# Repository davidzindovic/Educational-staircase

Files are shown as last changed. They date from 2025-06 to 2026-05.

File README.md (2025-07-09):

# Musical stairs with video effects
This project was constructed for use on the Faculty of Education, University of Ljubljana. The goal was to create attachable hardware to put onto an existing staircase (covering half the surface) with 2 turns and 25 steps.
Input data is processed by an ESP32, musical effects are played from an SD card with the help od MP3-TF player and visual effects are displayed on a projection/ screen via Raspberry Pi.
Data is transmitted from the ESP32 to RPI via Bluetooth.

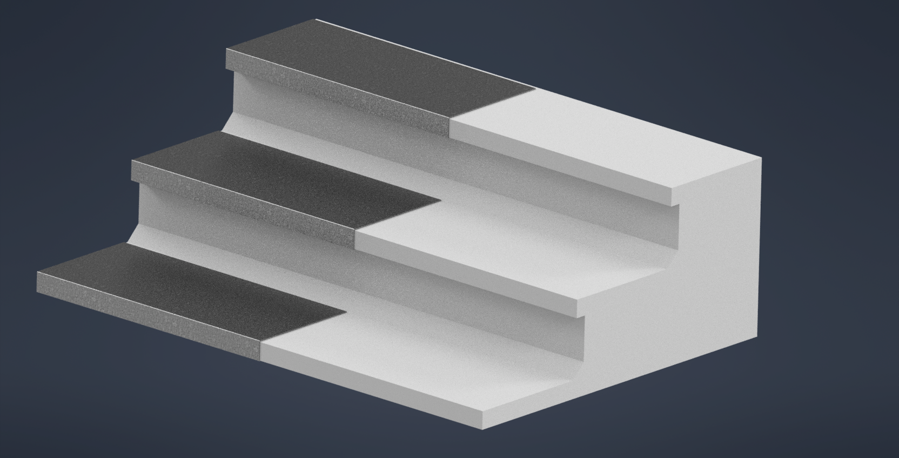
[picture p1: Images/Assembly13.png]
Part of the staircase with added hardware

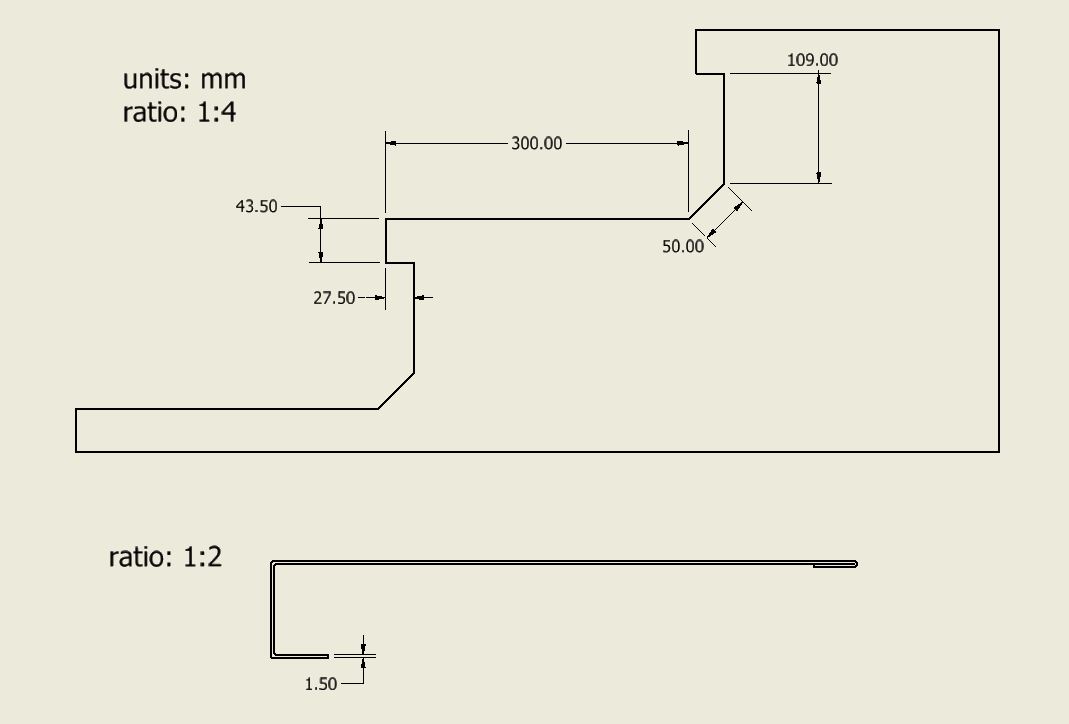
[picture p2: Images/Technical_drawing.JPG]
Technical Drawing


# Hardware
- ESP32
- MP3-TF player module
- Mux 4051
- Raspberry Pi 5
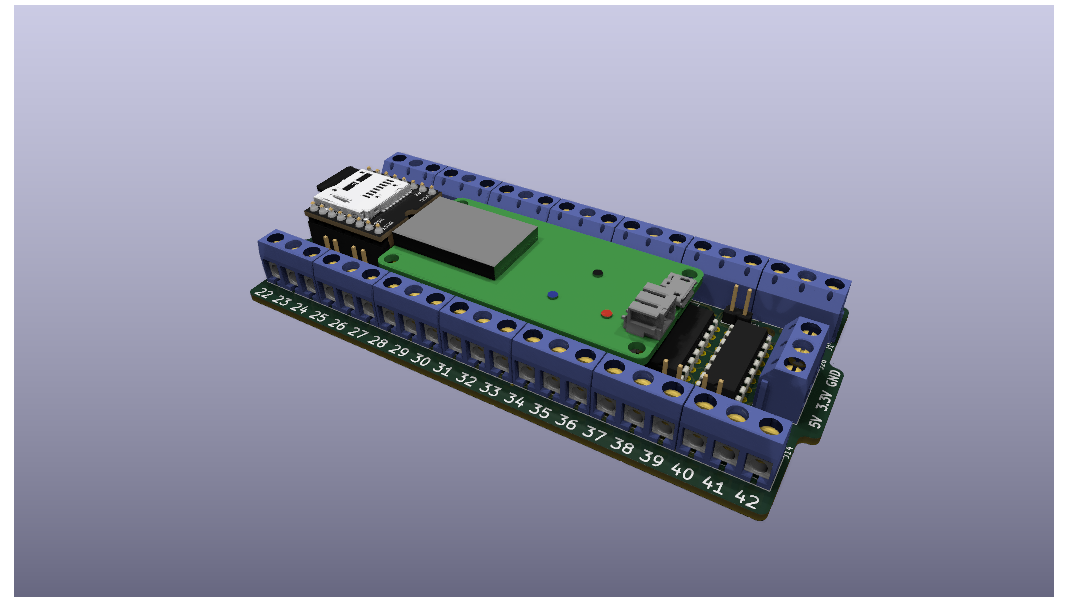
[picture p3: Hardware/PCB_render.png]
PCB render


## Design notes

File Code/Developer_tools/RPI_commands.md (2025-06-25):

# Launch python file

Do this in root (~$)
```
python -m venv name_of_virutal_env
source name_of_virtual_env/bin/activate
```
Now you should navigate to the folders/scripts.

# Transfer file from RPI to WIN PC
Putty should be installed on WIN PC prior to this step. Don't forget to check the "Add to PATH option".
```
pscp.exe pi_name@device name:_absolute_path_to_file absolute_path_to_paste_file
```

# Transfer file from WIN PC to RPI
```
scp absolute_path_to_file pi_name@device name:_absolute_path_to_paste_file
```

In both casses you will need to enter the RPI password, which will not be visible when typing.

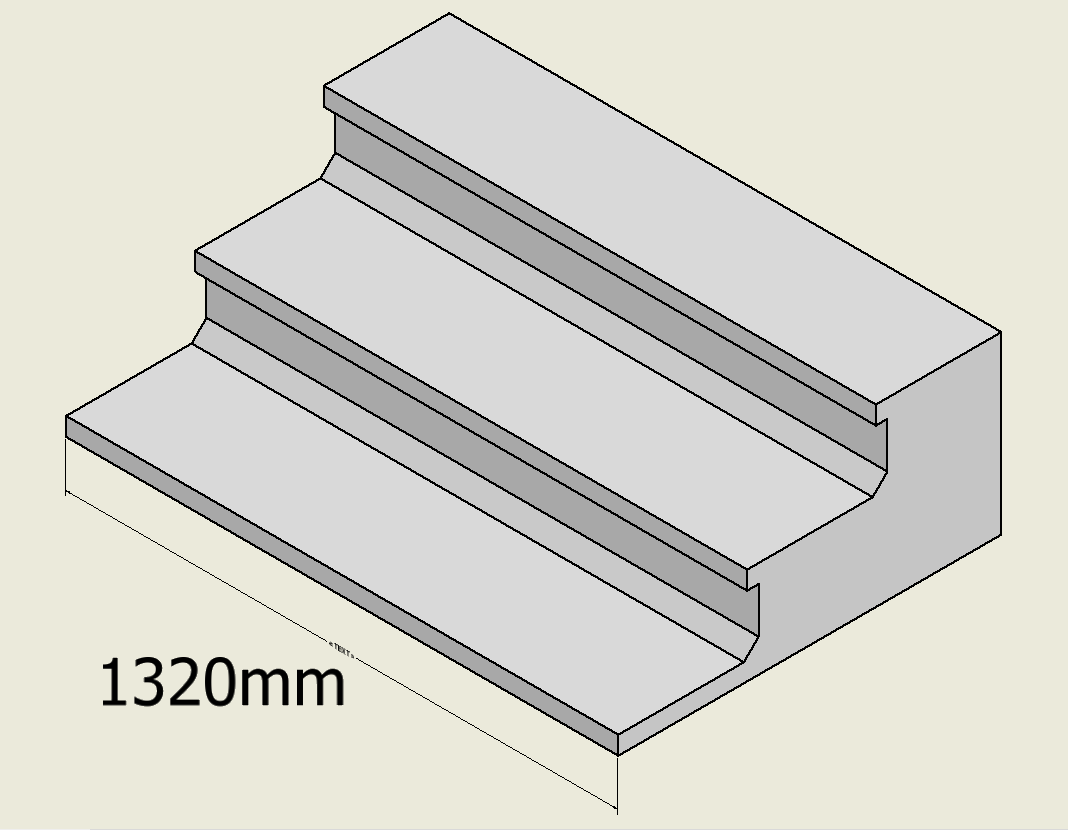
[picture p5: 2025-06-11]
Images/part_of_staircase.png

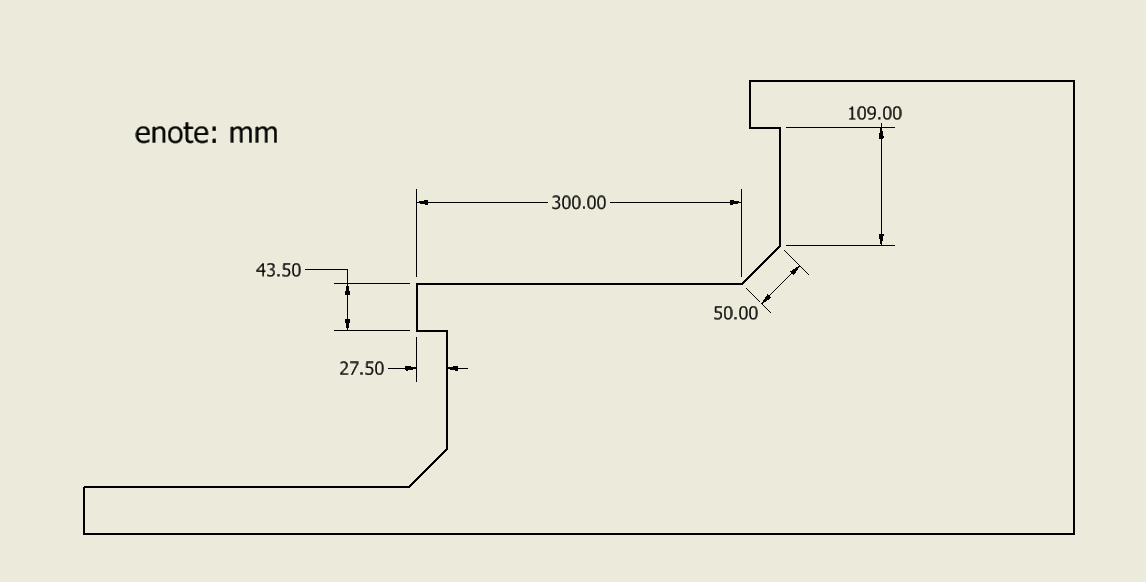
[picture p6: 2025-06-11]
Images/Staircase_dimensions.png

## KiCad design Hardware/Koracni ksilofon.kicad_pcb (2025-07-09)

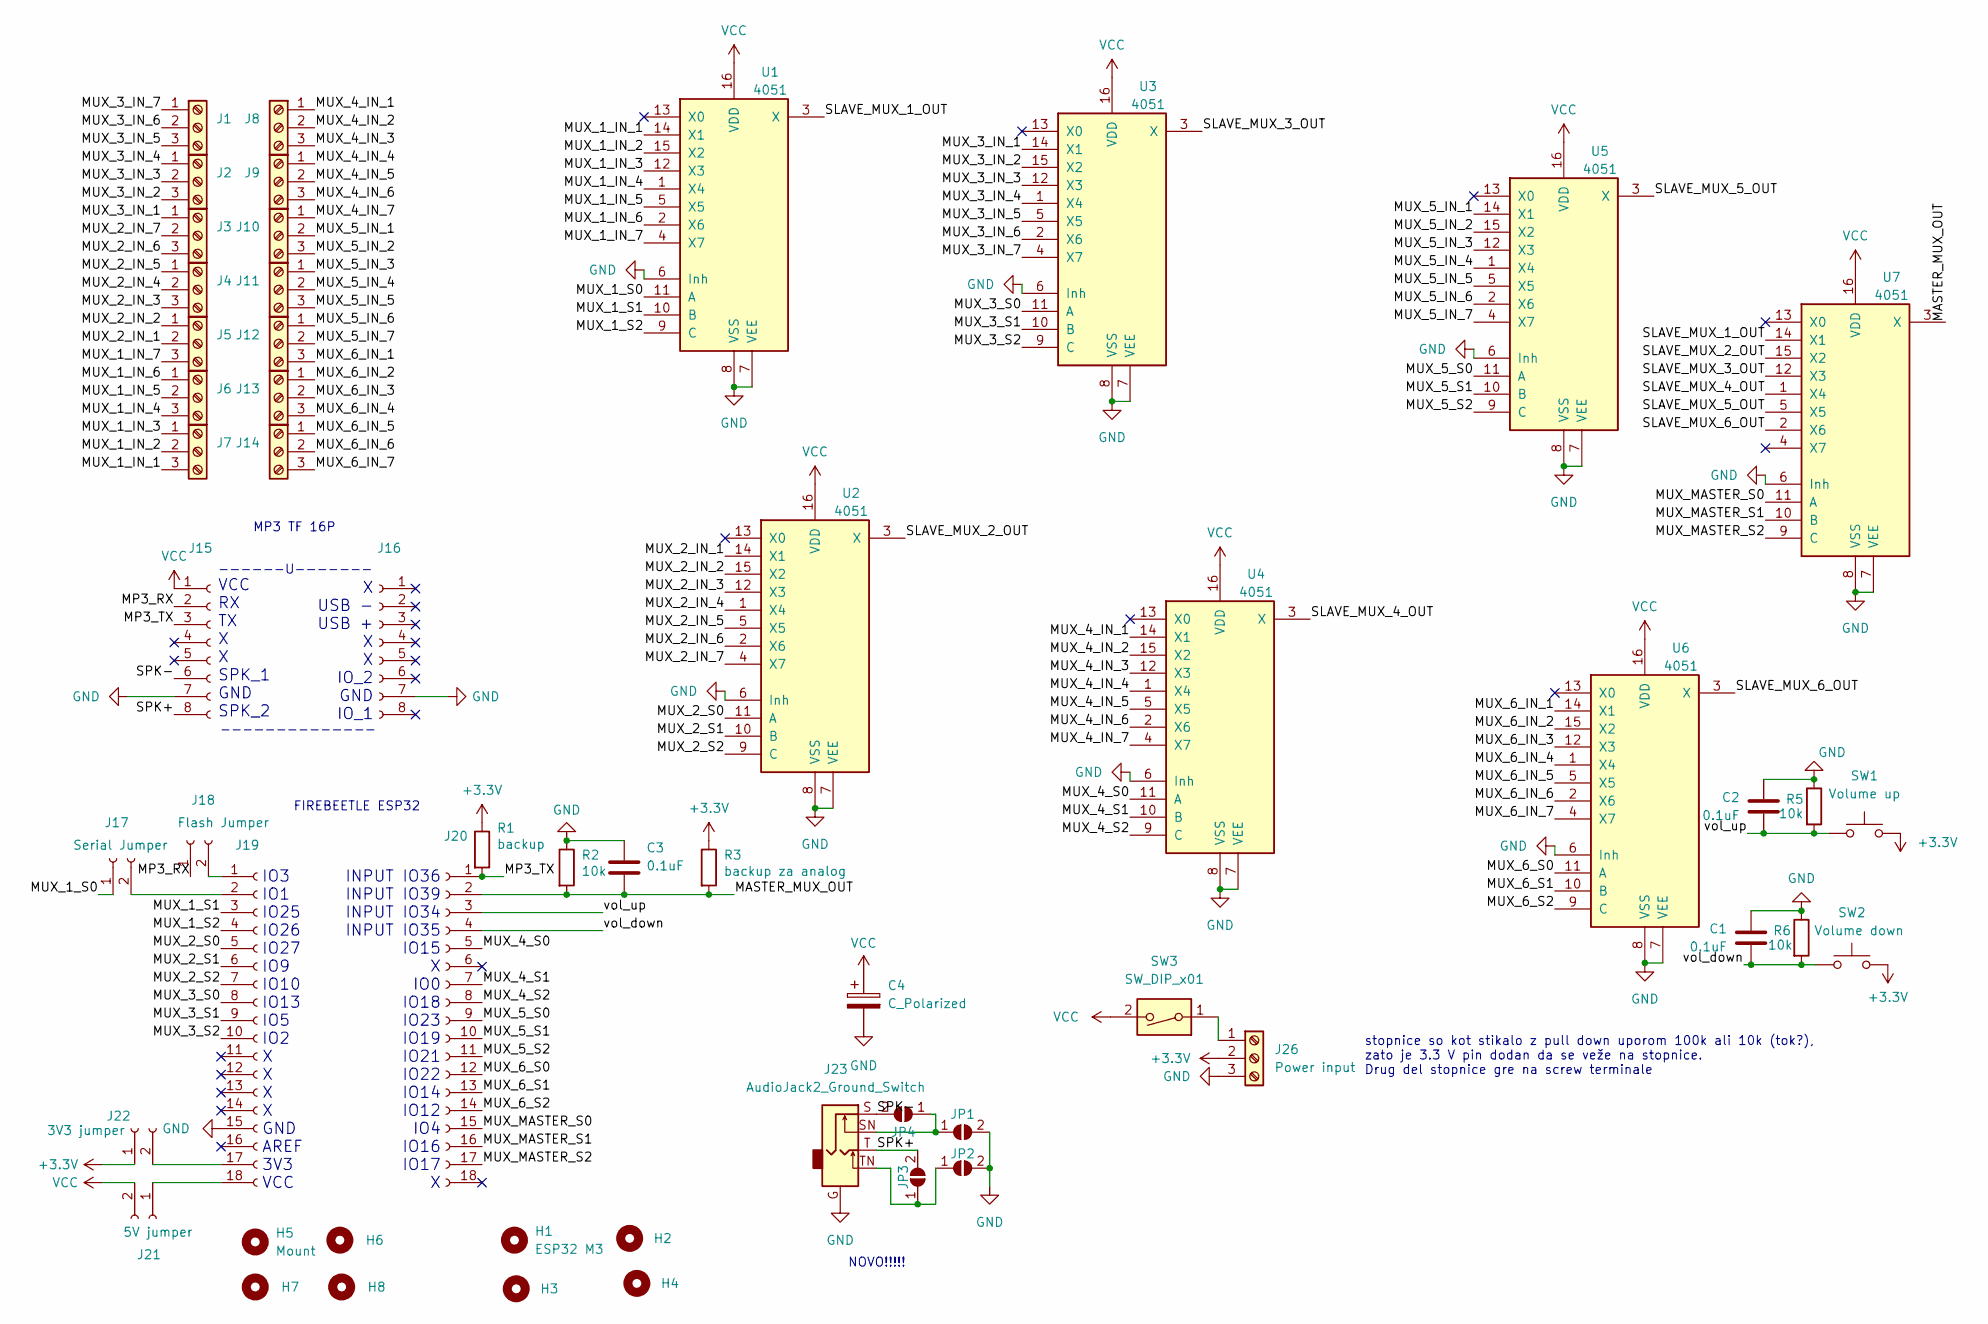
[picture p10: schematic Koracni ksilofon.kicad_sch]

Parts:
C1, C2, C3: 0.1uF; C_Disc_D3.4mm_W2.1mm_P2.50mm
C4: C_Polarized; CP_Radial_D5.0mm_P2.50mm
H1, H2, H3, H4: ESP32 M3; M3 luknja
H5, H6, H7, H8: Mount; MountingHole_3.2mm_M3
J1, J2, J3, J4, J5, J6, J7, J8, J9, J10, J11, J12, J13, J14: Screw_Terminal_01x03; TerminalBlock_bornier-3_P5.08mm
J15, J16: Conn_01x08_Socket; PinSocket_1x08_P2.54mm_Vertical
J17: Serial Jumper; PinHeader_1x02_P2.54mm_Vertical
J18: Flash Jumper; PinHeader_1x02_P2.54mm_Vertical
J19, J20: Conn_01x18_Socket; PinSocket_1x18_P2.54mm_Vertical
J21: 5V jumper; PinHeader_1x02_P2.54mm_Vertical
J22: 3V3 jumper; PinHeader_1x02_P2.54mm_Vertical
J23: AudioJack2_Ground_Switch; Audio jack connector
J26: Power input; TerminalBlock_bornier-3_P5.08mm
JP1, JP2, JP3, JP4: SolderJumper_2_Open; SolderJumper-2_P1.3mm_Open_TrianglePad1.0x1.5mm
R1: backup; R_Axial_DIN0207_L6.3mm_D2.5mm_P7.62mm_Horizontal
R2, R5, R6: 10k; R_Axial_DIN0207_L6.3mm_D2.5mm_P7.62mm_Horizontal
R3: backup za analog; R_Axial_DIN0207_L6.3mm_D2.5mm_P7.62mm_Horizontal
SW1: Volume up; PinHeader_1x02_P2.54mm_Vertical
SW2: Volume down; PinHeader_1x02_P2.54mm_Vertical
SW3: SW_DIP_x01; PinHeader_1x02_P2.54mm_Vertical
U1, U2, U3, U4, U5, U6, U7: 4051; DIP-16_W7.62mm

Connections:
+3.3V: J22.1, J26.2, R1.1, R3.1, SW1.2, SW2.2
/MASTER_MUX_OUT: C3.2, J20.2, R2.2, R3.2, U7.3 (X)
/MP3_RX: J15.2, J18.1
/MP3_TX: J15.3, J20.1, R1.2
/MUX_1_IN_1: J7.3, U1.14 (X1)
/MUX_1_IN_2: J7.2, U1.15 (X2)
/MUX_1_IN_3: J7.1, U1.12 (X3)
/MUX_1_IN_4: J6.3, U1.1 (X4)
/MUX_1_IN_5: J6.2, U1.5 (X5)
/MUX_1_IN_6: J6.1, U1.2 (X6)
/MUX_1_IN_7: J5.3, U1.4 (X7)
/MUX_1_S0: J17.1, U1.11 (A)
/MUX_1_S1: J19.3, U1.10 (B)
/MUX_1_S2: J19.4, U1.9 (C)
/MUX_2_IN_1: J5.2, U2.14 (X1)
/MUX_2_IN_2: J5.1, U2.15 (X2)
/MUX_2_IN_3: J4.3, U2.12 (X3)
/MUX_2_IN_4: J4.2, U2.1 (X4)
/MUX_2_IN_5: J4.1, U2.5 (X5)
/MUX_2_IN_6: J3.3, U2.2 (X6)
/MUX_2_IN_7: J3.2, U2.4 (X7)
/MUX_2_S0: J19.5, U2.11 (A)
/MUX_2_S1: J19.6, U2.10 (B)
/MUX_2_S2: J19.7, U2.9 (C)
/MUX_3_IN_1: J3.1, U3.14 (X1)
/MUX_3_IN_2: J2.3, U3.15 (X2)
/MUX_3_IN_3: J2.2, U3.12 (X3)
/MUX_3_IN_4: J2.1, U3.1 (X4)
/MUX_3_IN_5: J1.3, U3.5 (X5)
/MUX_3_IN_6: J1.2, U3.2 (X6)
/MUX_3_IN_7: J1.1, U3.4 (X7)
/MUX_3_S0: J19.8, U3.11 (A)
/MUX_3_S1: J19.9, U3.10 (B)
/MUX_3_S2: J19.10, U3.9 (C)
/MUX_4_IN_1: J8.1, U4.14 (X1)
/MUX_4_IN_2: J8.2, U4.15 (X2)
/MUX_4_IN_3: J8.3, U4.12 (X3)
/MUX_4_IN_4: J9.1, U4.1 (X4)
/MUX_4_IN_5: J9.2, U4.5 (X5)
/MUX_4_IN_6: J9.3, U4.2 (X6)
/MUX_4_IN_7: J10.1, U4.4 (X7)
/MUX_4_S0: J20.5, U4.11 (A)
/MUX_4_S1: J20.7, U4.10 (B)
/MUX_4_S2: J20.8, U4.9 (C)
/MUX_5_IN_1: J10.2, U5.14 (X1)
/MUX_5_IN_2: J10.3, U5.15 (X2)
/MUX_5_IN_3: J11.1, U5.12 (X3)
/MUX_5_IN_4: J11.2, U5.1 (X4)
/MUX_5_IN_5: J11.3, U5.5 (X5)
/MUX_5_IN_6: J12.1, U5.2 (X6)
/MUX_5_IN_7: J12.2, U5.4 (X7)
/MUX_5_S0: J20.9, U5.11 (A)
/MUX_5_S1: J20.10, U5.10 (B)
/MUX_5_S2: J20.11, U5.9 (C)
/MUX_6_IN_1: J12.3, U6.14 (X1)
/MUX_6_IN_2: J13.1, U6.15 (X2)
/MUX_6_IN_3: J13.2, U6.12 (X3)
/MUX_6_IN_4: J13.3, U6.1 (X4)
/MUX_6_IN_5: J14.1, U6.5 (X5)
/MUX_6_IN_6: J14.2, U6.2 (X6)
/MUX_6_IN_7: J14.3, U6.4 (X7)
/MUX_6_S0: J20.12, U6.11 (A)
/MUX_6_S1: J20.13, U6.10 (B)
/MUX_6_S2: J20.14, U6.9 (C)
/MUX_MASTER_S0: J20.15, U7.11 (A)
/MUX_MASTER_S1: J20.16, U7.10 (B)
/MUX_MASTER_S2: J20.17, U7.9 (C)
/SLAVE_MUX_1_OUT: U1.3 (X), U7.14 (X1)
/SLAVE_MUX_2_OUT: U2.3 (X), U7.15 (X2)
/SLAVE_MUX_3_OUT: U3.3 (X), U7.12 (X3)
/SLAVE_MUX_4_OUT: U4.3 (X), U7.1 (X4)
/SLAVE_MUX_5_OUT: U5.3 (X), U7.5 (X5)
/SLAVE_MUX_6_OUT: U6.3 (X), U7.2 (X6)
/SPK+: J15.8, J23.T, JP3.2 (B)
/SPK-: J15.6, J23.S, JP4.2 (B)
/vol_down: C1.2, J20.4, R6.2, SW2.1
/vol_up: C2.2, J20.3, R5.2, SW1.1
GND: C1.1, C2.1, C3.1, C4.2, J15.7, J16.7, J19.15, J23.G, J26.3, JP1.2 (B), JP2.2 (B), R2.1, R5.1, R6.1, U1.6 (Inh), U1.7 (VEE), U1.8 (VSS), U2.6 (Inh), U2.7 (VEE), U2.8 (VSS), U3.6 (Inh), U3.7 (VEE), U3.8 (VSS), U4.6 (Inh), U4.7 (VEE), U4.8 (VSS), U5.6 (Inh), U5.7 (VEE), U5.8 (VSS), U6.6 (Inh), U6.7 (VEE), U6.8 (VSS), U7.6 (Inh), U7.7 (VEE), U7.8 (VSS)
unnamed: J17.2, J19.2
unnamed: J18.2, J19.1
unnamed: J19.17, J22.2
unnamed: J19.18, J21.1
unnamed: J26.1, SW3.1
unnamed: J23.SN, JP1.1 (A), JP4.1 (A)
unnamed: J23.TN, JP2.1 (A), JP3.1 (A)
VCC: C4.1, J15.1, J21.2, SW3.2, U1.16 (VDD), U2.16 (VDD), U3.16 (VDD), U4.16 (VDD), U5.16 (VDD), U6.16 (VDD), U7.16 (VDD)

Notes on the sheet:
stopnice so kot stikalo z pull down uporom 100k ali 10k (tok?), zato je 3.3 V pin dodan da se veže na stopnice. Drug del stopnice gre na screw terminale
--------------
X USB - USB + X X IO_2 GND IO_1
NOVO!!!!!
FIREBEETLE ESP32
INPUT IO36 INPUT IO39 INPUT IO34 INPUT IO35 IO15 X IO0 IO18 IO23 IO19 IO21 IO22 IO14 IO12 IO4 IO16 IO17 X
IO3 IO1 IO25 IO26 IO27 IO9 IO10 IO13 IO5 IO2 X X X X GND AREF 3V3 VCC
MP3 TF 16P
VCC RX TX X X SPK_1 GND SPK_2
------U-------

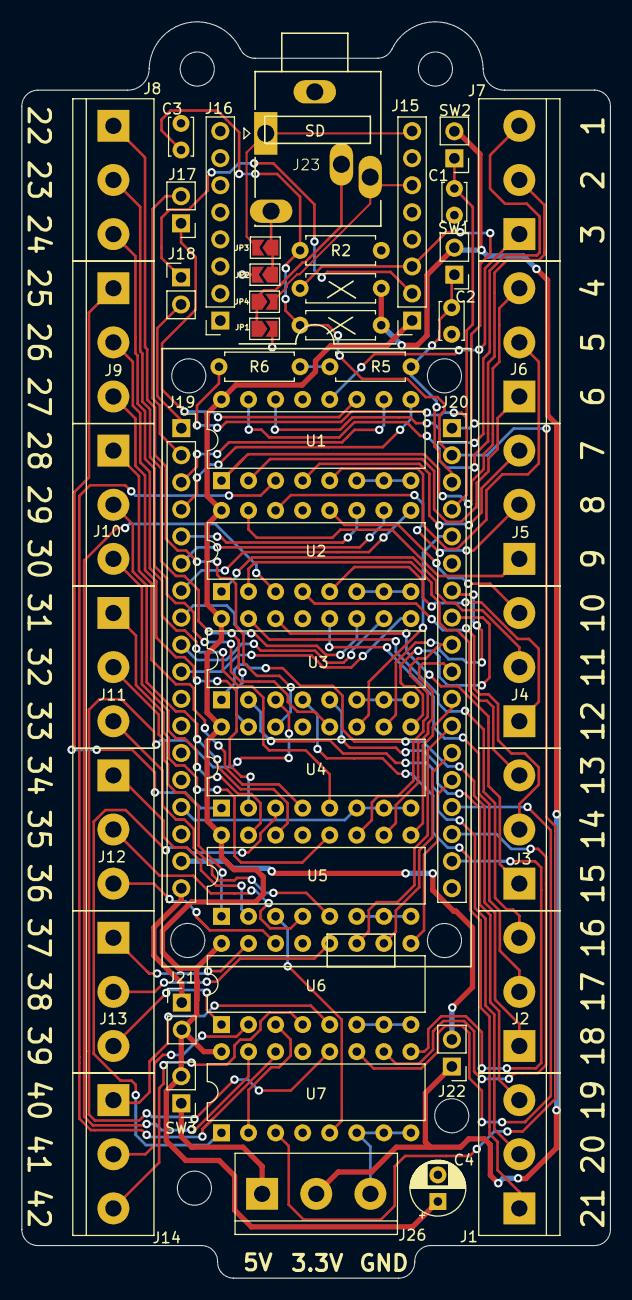
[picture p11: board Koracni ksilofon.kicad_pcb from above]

Board: 2 copper layers, 55.2 x 117.9 mm, 55 parts (0 on the bottom side), 86 nets.

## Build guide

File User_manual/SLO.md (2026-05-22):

# Navodila za uporabo
Didaktično stopnišče je nadgradnja obstoječega stopnišča, ki omogoča obogatitev sprehajalčeve poti po nadstropjih s pomočjo zvočnih in vizualnih učinkov. Korak na vsako stopnico sproži nov zvočni učinek, ki ga lahko odgovorna oseba spremeni z nalaganjem zvočnih datotek na SD kartico. Odziv na korak ni nujno le zvočen, saj v primeru prisotnosti primerno pripravljenega USB ključka se bodo tudi primerne vsebine predvajale na projekciji. Odgovorne osebe lahko pripravijo naloge (enačbe, povezovanje besed in slik, stopmotion, mešanje barv) ali pa diaprojekcijo.

# Zvočni učinki
Datoteke za zvočne učinke se bodo predvajale, ko stopimo na stopnico. V primeru, da se trenutna skladba še ni končala, in stopimo na naslednjo stopnico, potem bo trenutna skladba prekinjena in nova se bo predvajala.
Za prenos datotek za zvočne učinke na napravo uporabimo SD kartico.

### SD kartica
Opozorila:
- Na SD kartici naj bo največ 22 skladb (ker je 22 stopnic vse skupaj v uporabi).
  - SD kartico je potrebno v primeru nakupa nova SD kartice ponastaviti s pomočjo "SD Card Formatter".
- Skladbe morajo biti v formatu MP3.
  - To lahko preverite tako, da:
    * kliknete enkrat na datoteko (skladbo) z levim klikom
    * nato enkrat z desnim klikom
    * na dnu okenca kliknete "Lastnosti".
    * Če vidite kje napisano ".mp3", potem je datoteka pripravljena
  - V primeru, da vaša datoteka ni v formatu MP3, lahko vašo datoteko pretvorite v MP3 s pomočjo https://online-audio-converter.com/
  - Za lažje beleženja zaporedja zvokov lahko skladbe poimenujete s številkami ("1", "2" ...)
***

# Vizualni učinki
Datoteke za vizualne učinke se bodo predvajale glede na vaša navodila na USB ključku.
Možni vizualni učinki oz. aplikacije so:
- Enostavno mešanje barv
  - Vsak korak na stopnico doda eno barvo. Ko dosežemo mejo za barve, je prikazan rezultat. 
- Kompleksno mešanje barv
  - Vsak korak na stopnico doda eno barvo. Rezultat je prikazan sproti, aplikacija se ne konča, razen če uporabnik to zahteva
- Enačba
  - Korak na primerno stopnico predstavlja vnos rešitve. Pri tem lahko uporabimo le prvih deset stopnic (za vnos številk 0-9).
  - V primeru, da želimo vnesti večmestno številko, to storimo tako, da stopimo na stopnico za vnos vsake števke od leve proti desni.
- Povezovanje slik in besed
  - Korak na primerno stopnico (1 do x) predstavlja vnos rešitve
  - Slike morajo biti poimenovane s številko
  - Beseda mora biti v obliki sliki in poimenovana enako kot v ukazu
- Stopmotion
  - Začnemo s prvo sliko
  - Premik na naslednjo sliko dosežemo s korakom na naslednjo stopnico
  - Sliko lahko premaknemo nazaj s korakom na prješnjo stopnico
- Slideshow
  - Samodejno predvajanje videoposnetkov in/ali slik
  - Nastavljiv način

Opozorilo: Za izbiro barve uporabite Color Picker na Googlu: https://g.co/kgs/LrNHnkX . S pomočjo okna in drsnika izberite barvo in prekopirajte napis zapisan pod "HEX" (npr. #fcba03).

### Ukazi za vizualne učinke
Svoja navodila napišete tako, da v tekstovno datoteko "izvedba" na USB ključku vpišete ukaze v obliki, ki je primerna za aplikacijo:
- Enostavno mešanje barv: `barve:simple;število_možnih_vnosov!barva_hex_1,barva_hex_2`
  - Do vsake izmed napisanih HEX barv lahko dostopamo z eno stopnico.
  - primer: `barve:simple;3!#eb4034,#eb4034,#495446,#aba295,#8a6a91`
**slika primera**
- Kompleksno mešanje barv: `barve:complex;število_možnih_vnosov!barva_hex_1,barva_hex_2`
  - Do vsake izmed napisanih HEX barv lahko dostopamo z eno stopnico.
  - primer: `barve:complex;3!#eb4034,#eb4034,#495446,#aba295,#8a6a91`
**slika primera**
- Enačba: `enacba:ime_mape_s_slikami_stevilk;x+y_=z$resitev`
  - pri računu nam `_` skrije rešitev, vendar mora biti toliko znakov kot števk v rešitvi.
  - skrijemo lahko katerikoli del enačbe
  - na koncu moramo zapisati rešitev po `$`
  - primer: `enacba:naloga1;1+__=50$49`
**slika primera**
- Povezovanje slik in besed: `besedilna:ime_mape_s_slikami;ime_slike_z_napisom$stevilka_slike_ki_je_pravilna`
  - primer: `besedilna:naloga1;papagaj$3`
**slika primera**
- Stopmotion: `stopmotion:ime_mape_z_vsebino;neki?`
  - primer: `stopmotion:prva_animacija;1`
- Slideshow: `slideshow:ime_mape_z_vsebino;koliko_casa_naj_prikazuje_sliko$nacin_predvajanja`
  - nacini predvajanja:
    - 1 = le enkrat predvajaj samo slike
    - 2 = le enkrat predvajaj samo videoposnetke
    - 3 = le enkrat predvajaj slike in videoposnetke
    - 4 = ponavljaj predvajanje samo slik
    - 5 = ponavljaj predvajanje samo videposnetkov
    - 6 = ponavljaj predvajanje slik in videoposnetkov
  - primer `slideshow:ponedeljek;3$3`

### Preizkus ukazov za vizualne učinke

### USB ključek
Opozorila:
- USB ključek mora biti imenovan "stopnice"
  - USB ključek lahko preimenujete tako, da:
    * odprete Raziskovalec (ikona z mapico)
    * na levi strani najdete vstavljen USB ključek
    * enkrat z levim klikom kliknete na USB ključek
    * enkrat z desnim klikom kliknete na USB ključek
    * v oknu izberete "Preimenuj"
    * preminujete v "stopnice". Vse z majhnimi črkami!

#### Gradivo za naloge
Na USB ključku morate imeti vedno mape:
- besedilna
- enacba
- stopmomtion
- slideshow

in datoteko "izvedba.txt".
To je ključno, saj ukaz za nalogo bo iskal v točno imenovani mapi gradivo. Znotraj mape za posamezno vrsto naloge morate ustvariti svoje mape s poljubnim imenom, v katere lahko shranjujete slike (ali videje), ki so poimenovane primerno za ukaze.

**slika ureditve USB ključka tukaj**

# Delovanje naprave
Naprava je sestavljena iz dveh delov:
- prvi spremlja korakanje po stopnicah in predvaja zvok
- drugi prejema podatke o korakanju po stopnicah in prikazuje vizualne učinke

### Zvok/projekcija
Oba dela naprave se ob vklopu naprave povežeta. Za vklop zvoka je potrebno stikalo za zvok premakniti (pritisniti notri) na noto. Za vklop prikaza je potrebno stikalo za prikaz premakniti na projekcijo.

### Manjkajoč USB
Ob vklopu drugi del naprave prebere vsebino USB ključka in samodejno začne z izvajanjem nalog. V primeru, da USB ključek ob vklopu ni vstavljen ali pa če USB ključek med delovanjem odstranite, se bo prikazalo ozadje (PEF logo). Če USB ni bil vstavljen ob vklopu, se bo program samodejno zagnal nekaj sekund po vstavitvi USB ključka. Če ste USB ključek odstranili med delovanjem naprave ali pa po zaključku delovanja programa, je potrebno po ponovni vstavitvi program ponovno zagnati (glej naslednje poglavje).

### Prekinitev in ponovni zagon
Prekinitev delovanja aplikacije brez konca (kompleksno mešanje barv, stopmotion, slideshow) dosežemo tako, da petkrat zapored stopimo na zadnjo (22.) stopnico. Program ponovno zaženemo tako, da petkrat stopimo na tretjo (3.) stopnico.

Če želimo napravo ponovno zagnati, je potrebno stikalo za vklop naprave premakniti v lego, da bo spodnji del notri pritisnjen (ugasnjeno stanje), nato počakati vsaj 5 sekund in nato premakniti stikalo v nasprotno pozicijo (vklopljeno stanje).

### Težave
V primeru, da naprava za projekcijo ne bo imela povezave z napravo za zvok in branje stanja stopnic, bo na projekciji prikazan napis "". V tem primeru je potrebno ponovno zagnati napravo za projekcijo ali celotno napravo.

# Okolje za preizkus gradiva za didaktične stopnice

Okolje za preizkus gradiva za didaktične stopnice je obliki zagonske programske datoteke (.exe), ki jo lahko zaženemo z dvojnim levim klikom na datoteko.
Za preizkus je potrebno imeti gradivo pripravljeno na USB ključku, kot bi želeli zadevo pognati na nameščeni opremi na stopnišču (imenovanje, datoteke...).
Tekom preizkušanja je mišljeno, da vnose stopnic simuliramo preko tipkovnice s pritiskom na tipko. Med pritiski pustite nekaj časa za uspešno procesiranje vnosa. Za izhod lahko namesto vnosa "25" pritisnete tipko "ESC", pri čemer je še vedno potrebno pritisniti omenjeno tipko petkrat.
Na koncu preizkusa bo prikazan logotip Pedagoške Fakultete. V primeru vnosa obstaja možnost, da se bo okno "sesulo", ker je konec programa. V primeru nenavadnega delovanja, lahko zaprete okno s pomočjo miške.
- Opozorilo: uporaba tipkovnice je onemogočena v času delovanja programa, zato karkoli vnesete preko tipkovnice, bo program vzel kot njemu namenjen vnos.
- Opozorilo: program je trenutno prilagojen le za Windows okolje.

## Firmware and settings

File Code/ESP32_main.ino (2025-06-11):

#include <Arduino.h>
#include <DFPlayerMini_Fast.h>
#include "CD74HC4051E_lib.h"

#include "BluetoothSerial.h"
#include "esp_bt_device.h"

#if !defined(CONFIG_BT_ENABLED) || !defined(CONFIG_BLUEDROID_ENABLED)
#error Bluetooth is not enabled! Please run `make menuconfig` to and enable it
#endif

BluetoothSerial SerialBT;

//druga knjiznica za mp3 player
//potrebno installat firetimer.h

#define READ_PIN 39
#define NUM_INPUTS 25
#define NUM_CHIPS 5

#define DEBUG_MAIN 1

#define RXD2 36
#define TXD2 3
DFPlayerMini_Fast myMP3;

// S2, S1, S0
uint8_t master_mux_array[]={17,16,4};
uint8_t input_mux_array[]={/*26,25,1,*/10,9,27,2,5,13,18,0,15,21,19,23,12,14,22};
//pini od mux1 zakomentirani za serial izpis

uint8_t input_remap[25]={9,10,11,12,13,14,15,16,17,18,19,20,21,22,23,24,25,1,2,3,4,5,6,7,8};

void printDeviceAddress() {
 
  const uint8_t* point = esp_bt_dev_get_address();
 
  for (int i = 0; i < 6; i++) {
 
    char str[3];
 
    sprintf(str, "%02X", (int)point[i]);
    Serial.print(str);
 
    if (i < 5){
      Serial.print(":");
    }
 
  }
}

void setup()
{
  #if DEBUG_MAIN
  Serial.begin(115200);
  #endif

  Serial2.begin(9600, SERIAL_8N1, RXD2, TXD2);
  myMP3.begin(Serial2, false);  
  SerialBT.begin("ESP_stopnice"); //Bluetooth device name

    if(mux_checkup(NUM_INPUTS,NUM_CHIPS,input_mux_array,master_mux_array))
  {
    while(1){}
  }
  
  pinMode(READ_PIN,INPUT);
  
  for(int master=0;master<sizeof(master_mux_array);master++)
  {
    pinMode(master_mux_array[master],OUTPUT);
  }
  
  for(int input=0;input<sizeof(input_mux_array);input++)
  {
    pinMode(input_mux_array[input],OUTPUT);
  }


}

void loop()
{

static bool first=1;
static bool tog=0;
  static uint64_t pins_copy=0;
  static uint64_t pins=0;
  
  pins=digital_pin_check(NUM_INPUTS, NUM_CHIPS,input_mux_array,master_mux_array,READ_PIN);
  if(first)
  {first=0;}
  else
  {
  if(pins!=pins_copy)
  {
    uint64_t change=pins^pins_copy; // XOR checks change of state

    //SerialBT.write(pins);

    for(int q=0;q<  (NUM_INPUTS+1);q++)
    {
      if((change&(1<<q))>0 && !(pins_copy&(1<<q))) 
      {
        myMP3.play(q);

        if(SerialBT.available())
        {
          //q-1 zaradi začetnega indeksa 0
          SerialBT.write(input_remap[q-1]);
          SerialBT.flush();
        }
        else delay(20);

        #if DEBUG_MAIN
        Serial.print("Skladba: ");
        Serial.println(input_remap[q-1]);
       // Serial.println(change);
        #endif
        
      }
    }
    /*
    #if DEBUG_MAIN
    
    for(int debug=0;debug<NUM_INPUTS;debug++)
    {
      Serial.print(pins&(1<<debug));
    }
    Serial.print(uint16_t(pins),BIN);
    Serial.print("  ");
    Serial.print(uint16_t(pins_copy),BIN);
    Serial.print("  ");
    Serial.println(uint16_t(change),BIN);
    #endif
    */
  }
  } 

  //Serial.println(uint16_t(pins),BIN);
  pins_copy=pins;

/*
static int cnt=0;
static bool smer=0;
myMP3.play(1);
delay(100);
if(cnt<14 && !smer){myDFPlayer.volumeUp();cnt++;}
else if(cnt==14 && !smer) smer=1;
else if(cnt>-14 && smer){myDFPlayer.volumeDown();cnt--;}
else if(cnt==-14 && smer) smer=0; 
Serial.println(cnt);Serial.println(smer);
delay(100);
*/
}

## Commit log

2025-06-11 Rename shema koracni ksilofon.PNG to PCB/shema koracni ksilofon.PNG
2025-07-09 Rename shema koracni ksilofon.PNG to Schematic.PNG
